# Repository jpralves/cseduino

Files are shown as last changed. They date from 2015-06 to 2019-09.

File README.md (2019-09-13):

# CSEduino

Build your Arduino from scratch - projects

See more info at http://jpralves.net/cseduino/

This tree is organized in the following way:

- ~[projects](projects) - projects created with CSEDuino board~ (Not yet)
- [boards](boards) - Designs of PCB boards for CSEduino v3 and v4 (Kicad Format)
- [workshop](workshop) - Exercises for Workshops

## The V3 Board:

Board with components:

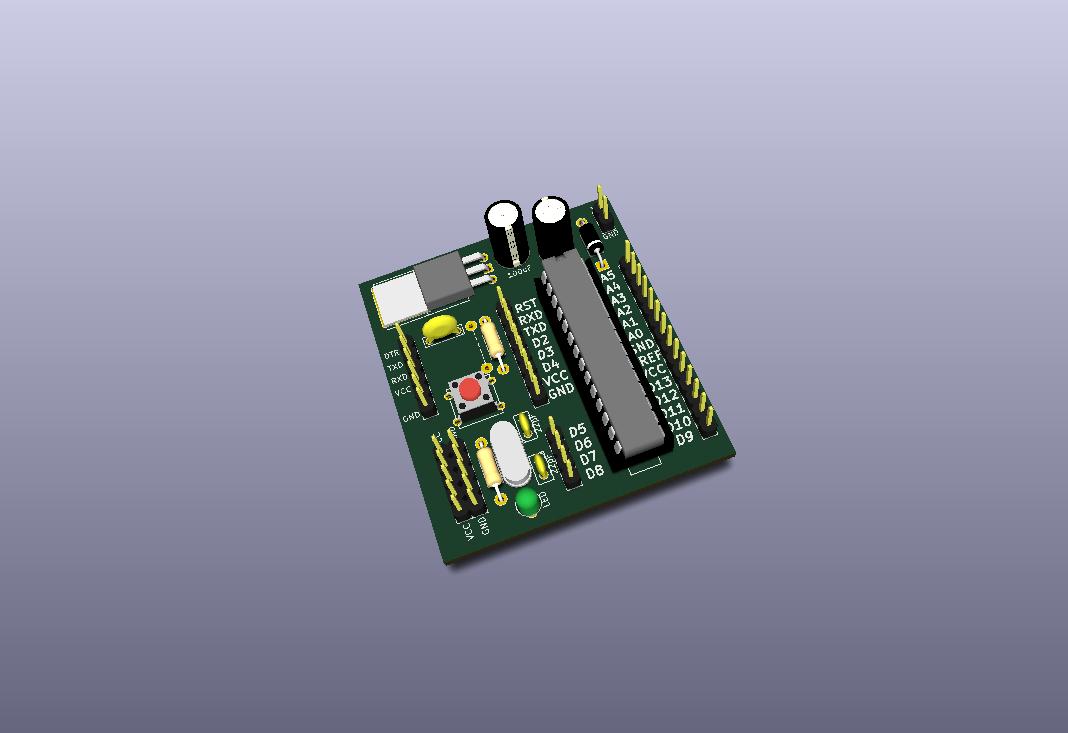
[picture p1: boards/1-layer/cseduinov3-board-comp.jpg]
cseduinov3-board-comp


## The v4 Board:

Board with components:

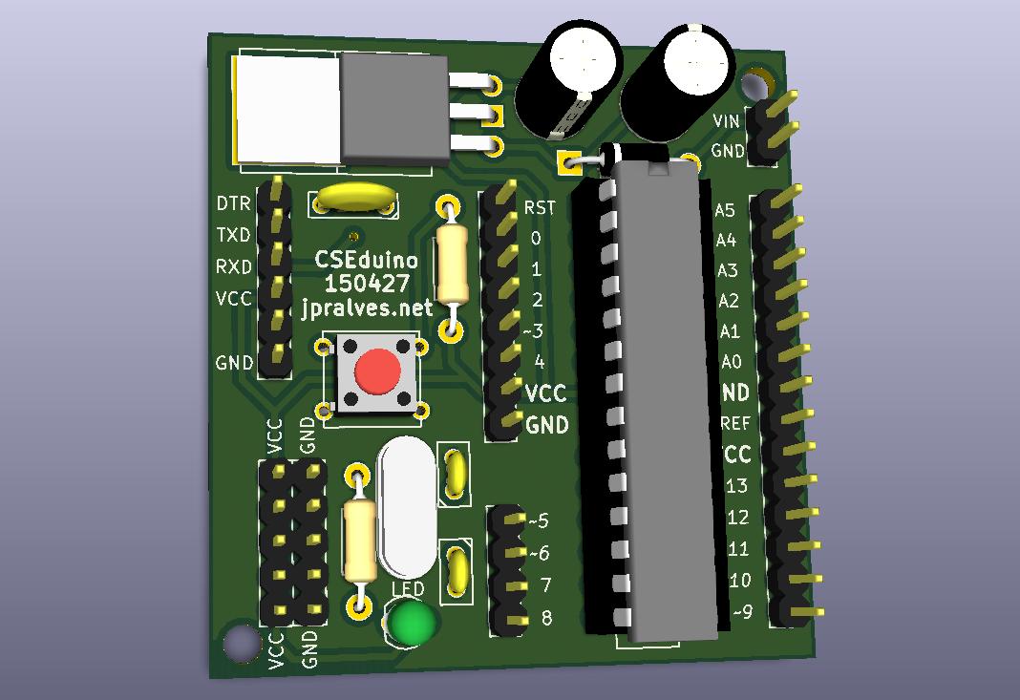
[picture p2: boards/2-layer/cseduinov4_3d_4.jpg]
cseduinov4-board-comp


Front of the board:

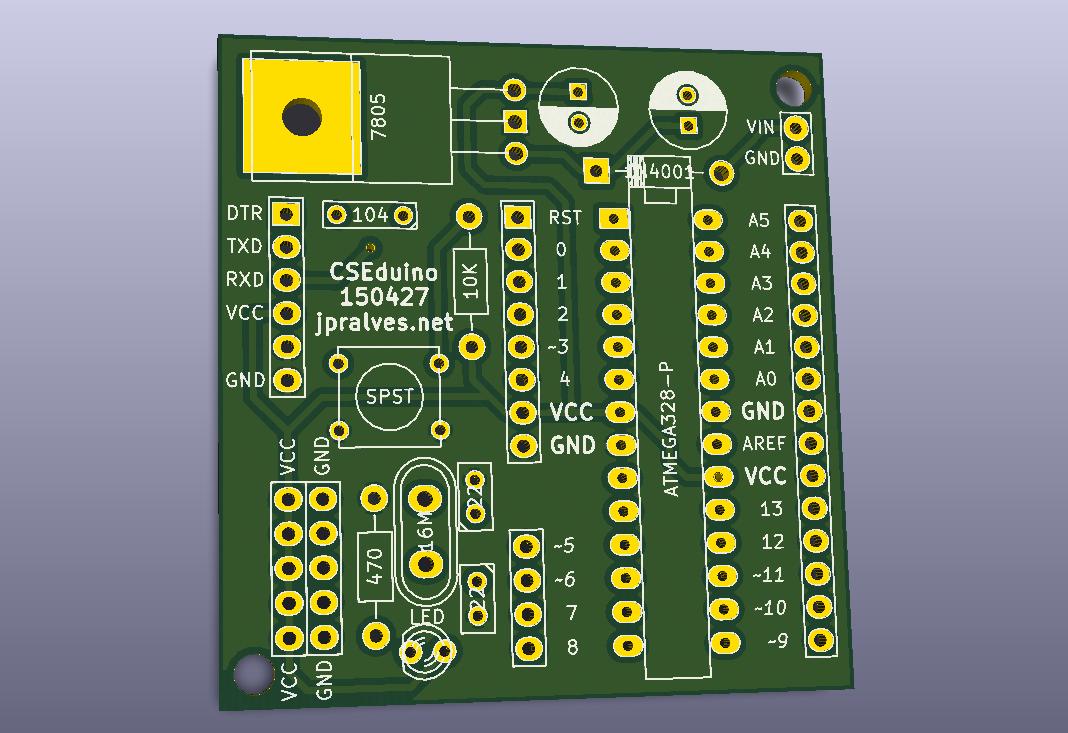
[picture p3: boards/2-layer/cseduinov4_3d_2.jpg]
cseduinov3-board


Back of the board:

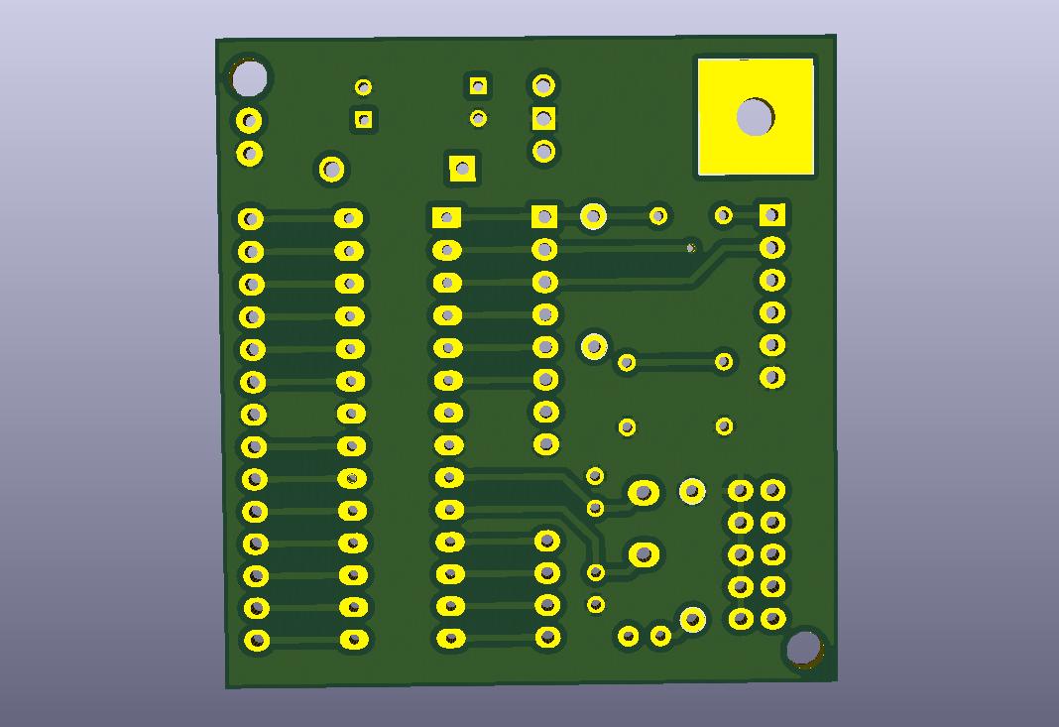
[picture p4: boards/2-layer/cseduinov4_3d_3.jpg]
cseduinov3-board-back


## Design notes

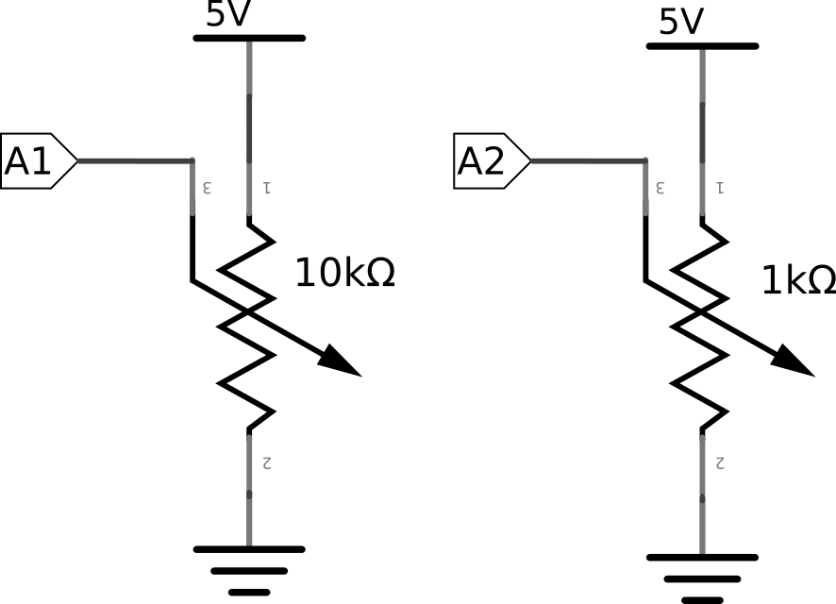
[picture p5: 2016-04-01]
workshop/2016-04-02/Theremin/VR.png

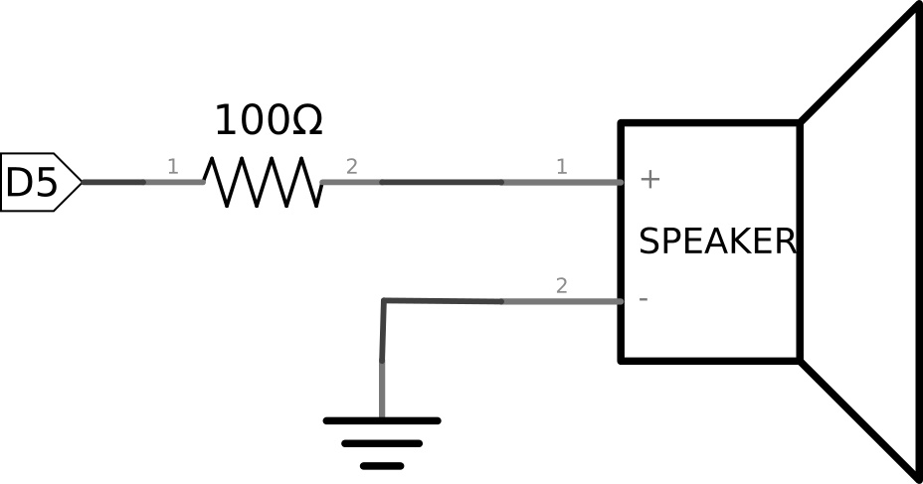
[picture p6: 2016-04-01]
workshop/2016-04-02/Morse/Buzzer.png

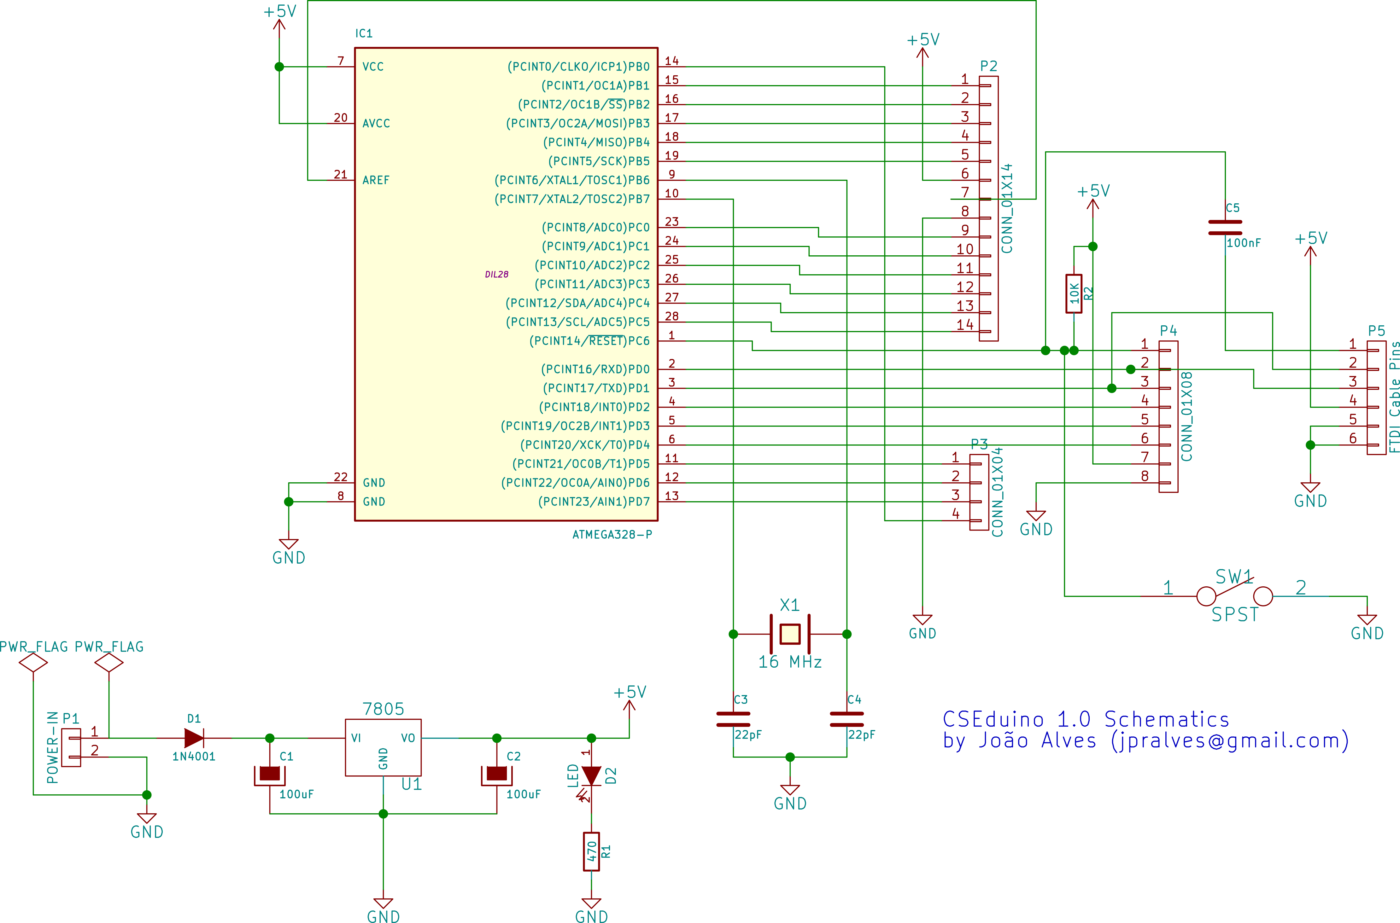
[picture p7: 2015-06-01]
boards/1-layer/cseduinov3.sch.png

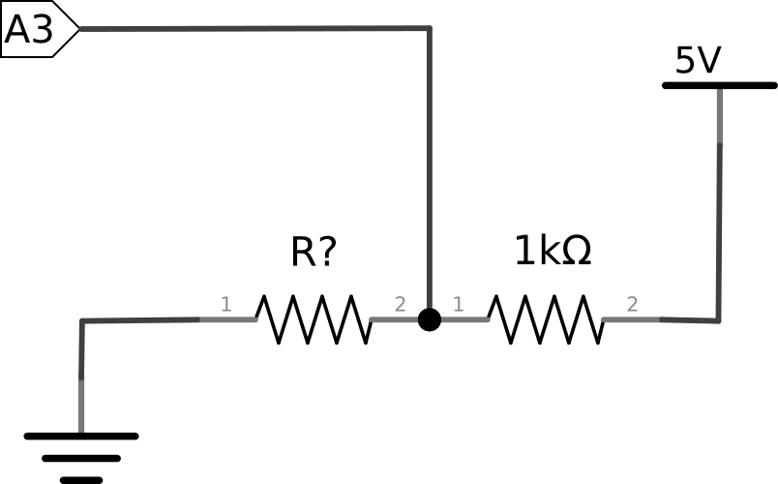
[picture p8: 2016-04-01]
workshop/2016-04-02/OhmMeter/OhmMeter.png

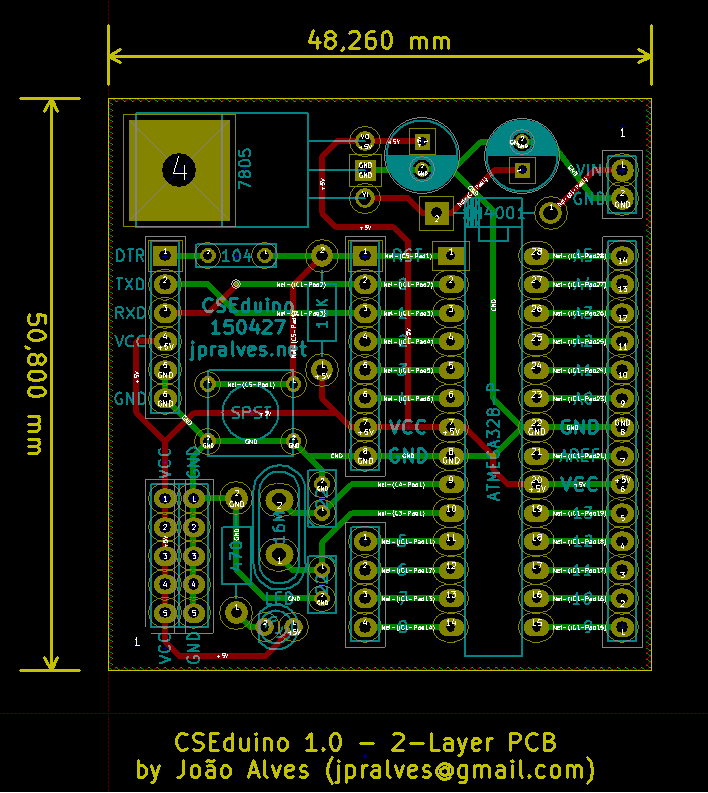
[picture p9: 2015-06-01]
boards/2-layer/cseduinov4.kicad_pcb2.png

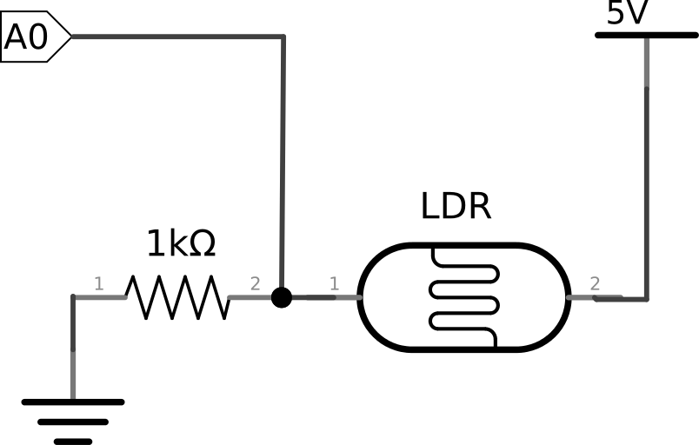
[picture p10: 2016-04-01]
workshop/2016-04-02/Photoresistor/Photoresistor.png

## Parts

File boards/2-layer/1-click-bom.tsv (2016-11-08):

References | Qty | Mouser | Description
C2, C1 | 2 | 667-ECA-1EM101 | CAPAPOL 100uF
C3, C4 | 2 | 594-CN15A220J | C 22pF Unpolarized capacitor
C5 | 1 | 594-D103Z25Z5VF63L6R | C 100nF Unpolarized capacitor
D1 | 1 | 863-1N4001G | DIODE 1N4001
D2 | 1 | 696-SLX-LX3044HD | LED
IC1 | 1 | 556-ATMEGA328P-PU | ATMEGA328P-PU PDIP28 Narrow, 16k Flash, 1kB SRAM, 512B EEPROM DIL28
IC1_SOCKET | 1 | 571-1-2199298-9 | 28P DIP SKT 300 CL LADDER
P2 | 1 | 855-M20-7821446 | CONN 01X14 Connector, single row, 01x14
P3 | 1 | 855-M20-7820446 | CONN 01X04 Connector, single row, 01x04
P4 | 1 | 855-M20-7820842 | CONN 01X08 Connector, single row, 01x08
P1 | 1 | 571-4-146278-0 | CONN 01X06 FTDI Cable Pins Connector, single row, 01x06
R1 | 1 | 603-MFR-25FBF52-470R | R 470 Resistor
R2 | 1 | 603-MFR-25FBF52-10K | R 10K Resistor
SW1 | 1 | 653-B3W-1002 | SPST Interrupteur simple
U1 | 1 | 863-NCP7805TG | 7805 Linear Regulator +5V
X1 | 1 | 520-160-20-46X | CRYSTAL 16.0000MHZ 18PF T/H

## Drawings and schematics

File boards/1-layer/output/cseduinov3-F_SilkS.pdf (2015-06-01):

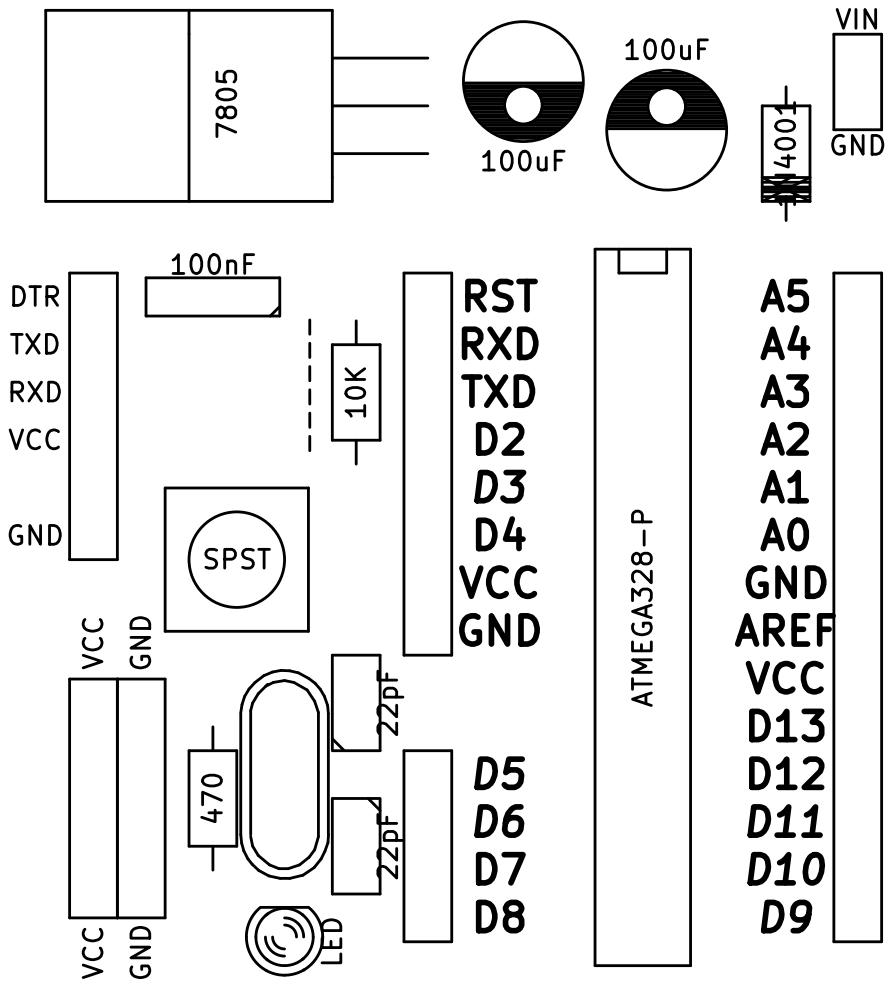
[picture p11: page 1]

VIN GND VCC GND GND
SPST7805

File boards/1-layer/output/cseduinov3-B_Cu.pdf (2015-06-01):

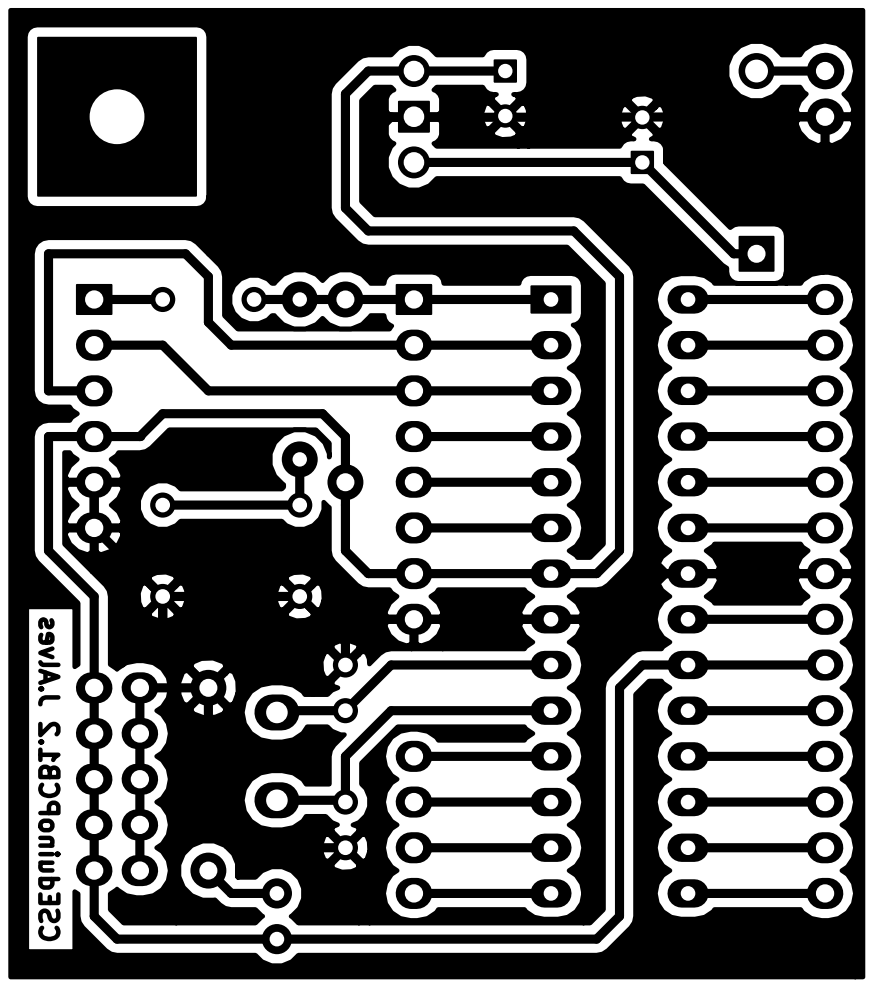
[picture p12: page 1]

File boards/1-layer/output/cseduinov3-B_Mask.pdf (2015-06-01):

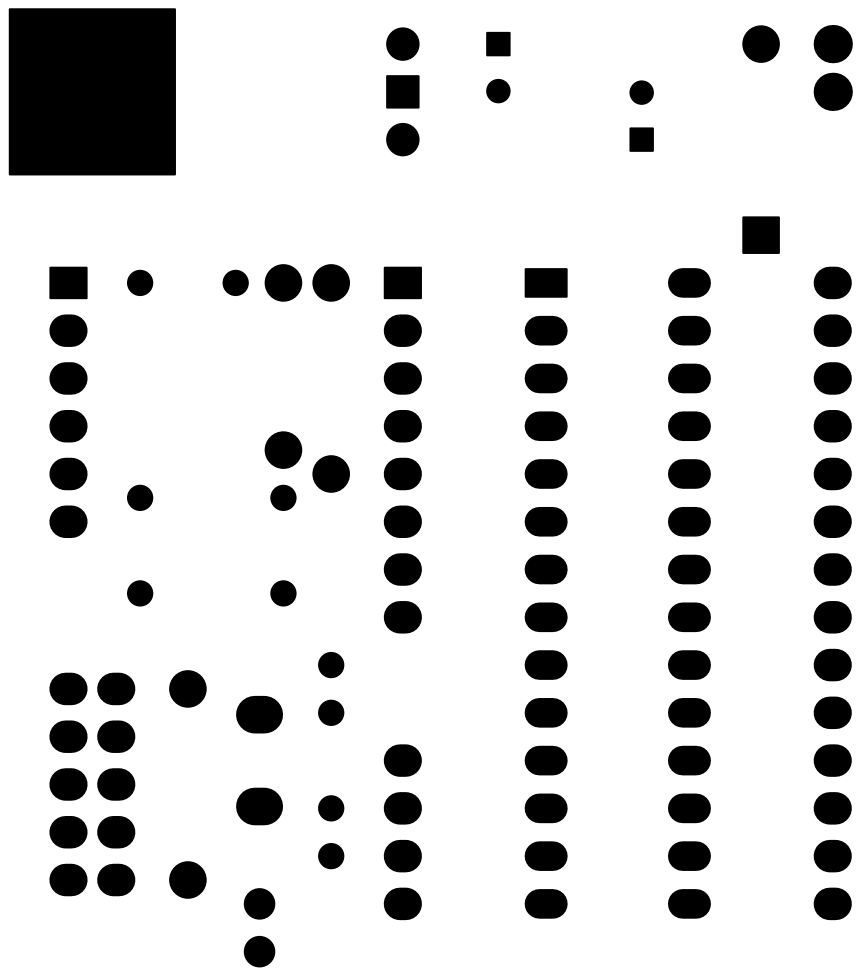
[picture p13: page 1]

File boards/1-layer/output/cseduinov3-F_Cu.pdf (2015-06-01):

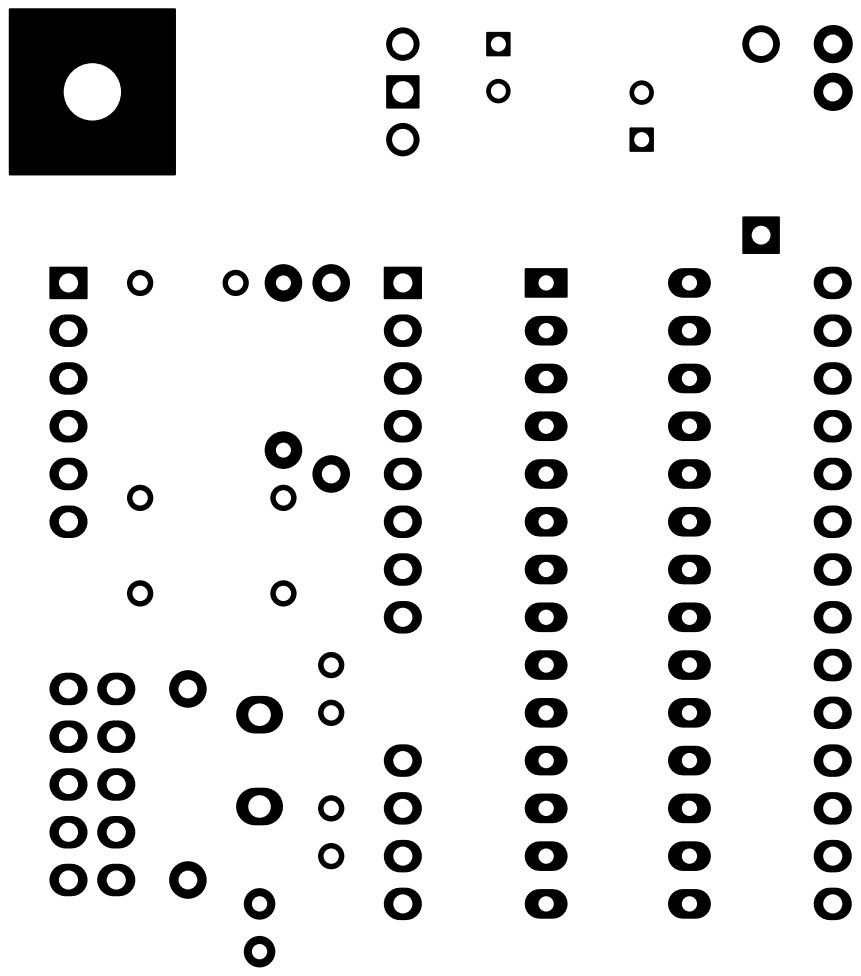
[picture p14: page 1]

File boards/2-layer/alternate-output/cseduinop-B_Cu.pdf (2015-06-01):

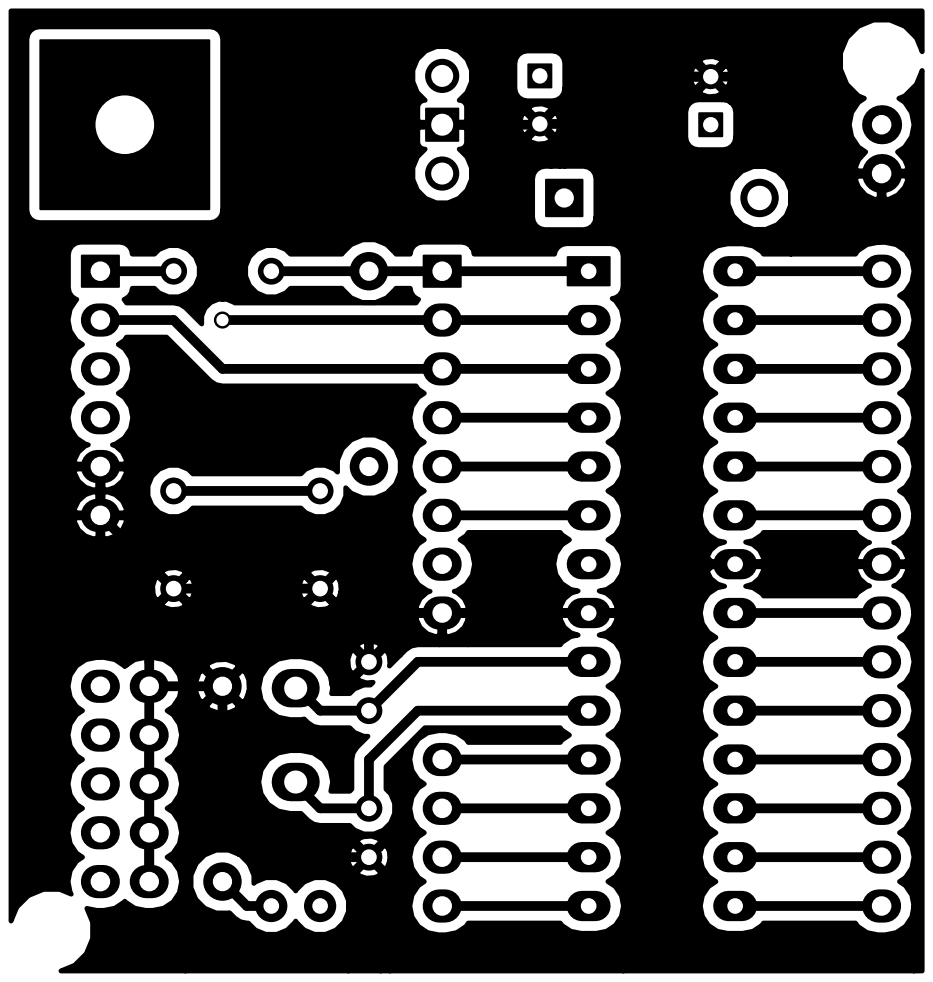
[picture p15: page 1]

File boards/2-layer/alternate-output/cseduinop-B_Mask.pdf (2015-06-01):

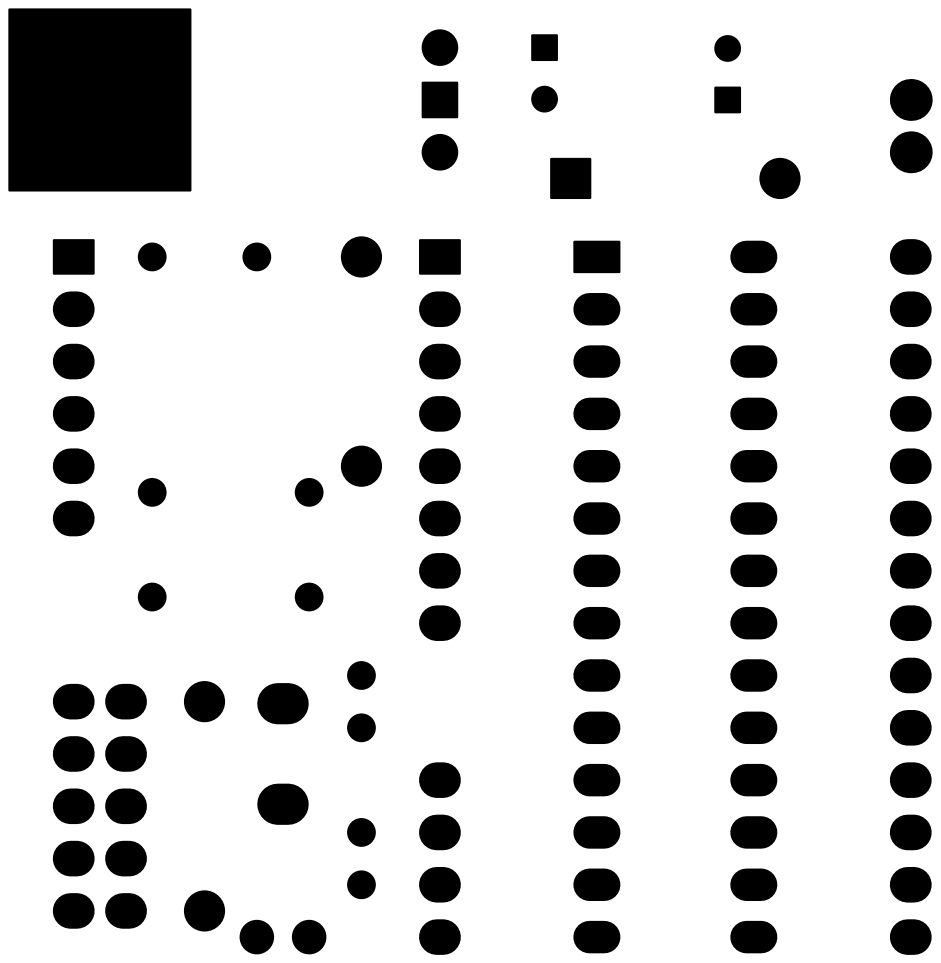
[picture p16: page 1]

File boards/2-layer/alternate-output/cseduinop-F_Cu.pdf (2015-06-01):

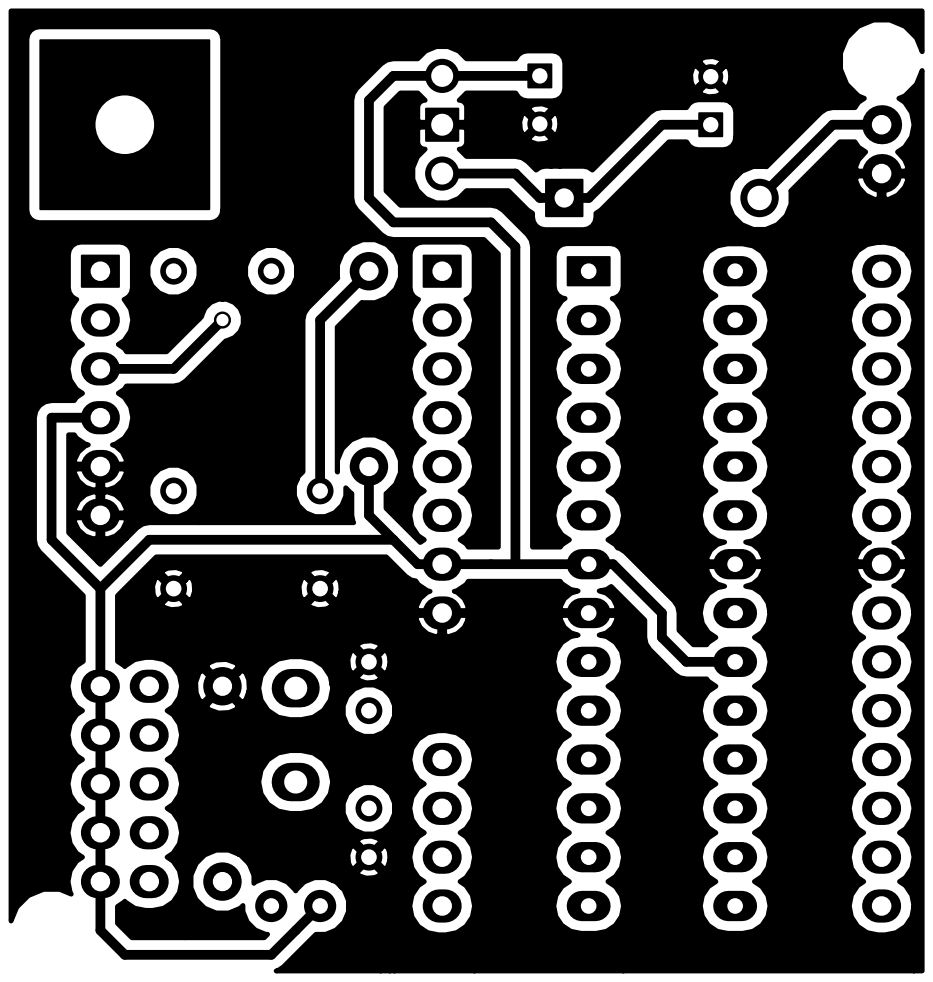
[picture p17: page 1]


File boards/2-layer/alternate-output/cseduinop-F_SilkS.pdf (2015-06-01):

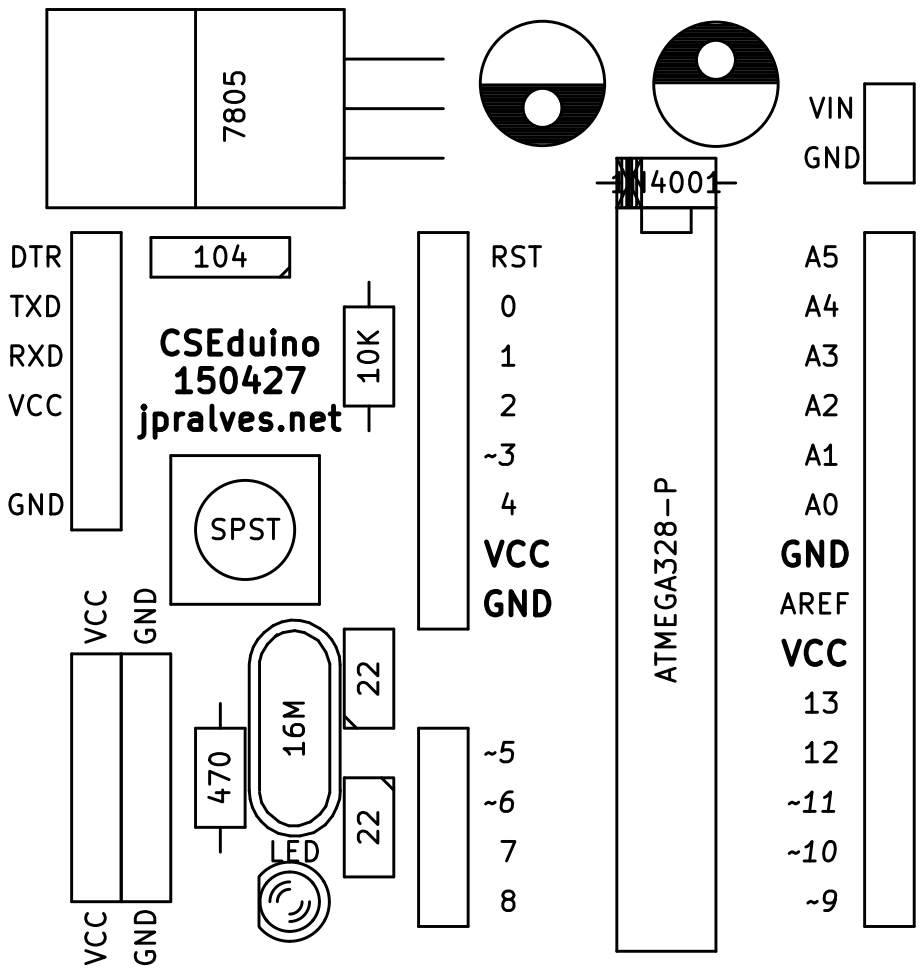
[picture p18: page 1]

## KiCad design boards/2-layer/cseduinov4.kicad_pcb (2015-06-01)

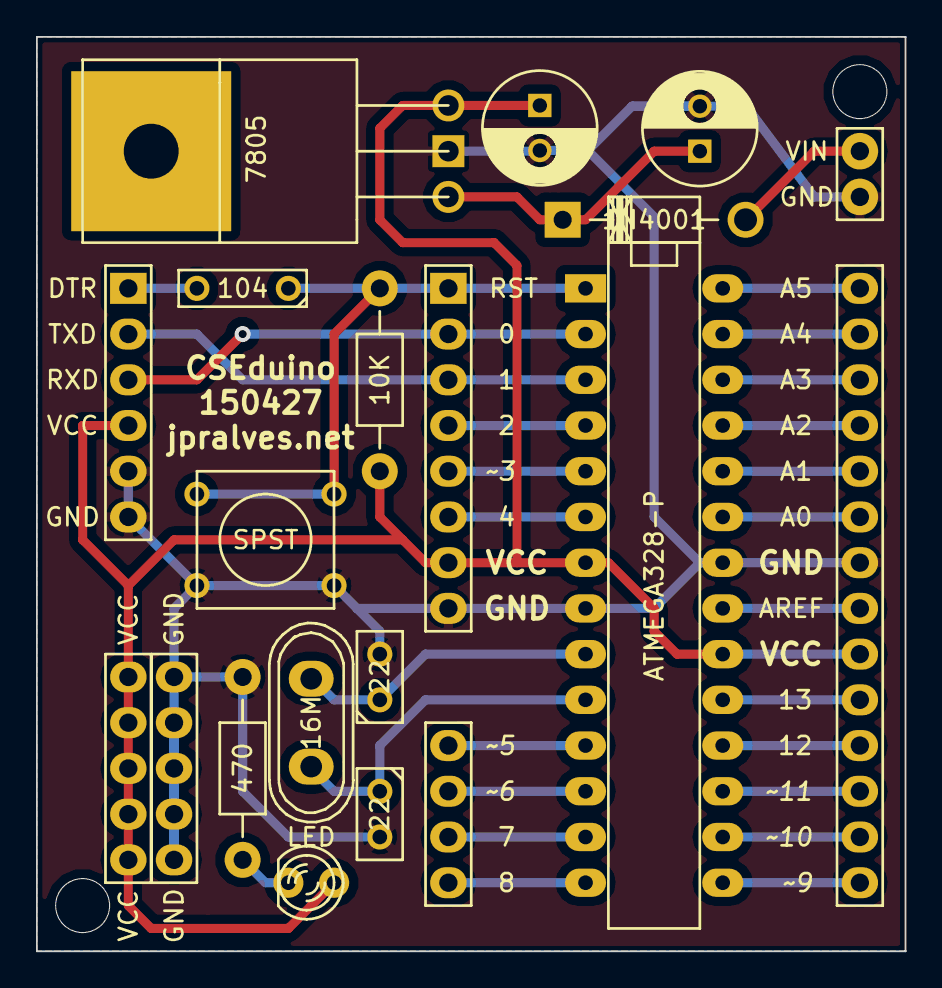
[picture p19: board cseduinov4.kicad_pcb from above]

Board: 2 copper layers, 48.3 x 50.8 mm, 18 parts (0 on the bottom side), 30 nets.

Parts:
C1, C2: 100uF; C_Radial_D6.3_L11.2_P2.5
C3, C4: 22; C1
C5: 104; C2
D1: 1N4001; Diode_DO-41_SOD81_Horizontal_RM10
D2: LED; LED-3MM
IC1: ATMEGA328-P; DIP-28__300_ELL
P1: CONN_01X02; Pin_Header_Straight_1x02
P2: CONN_01X14; Pin_Header_Straight_1x14
P3: CONN_01X04; Pin_Header_Straight_1x04
P4: CONN_01X08; Pin_Header_Straight_1x08
P5: CONN_01X06; Pin_Header_Straight_1x06
R1: 470; Resistor_Horizontal_RM10mm
R2: 10K; Resistor_Horizontal_RM10mm
SW1: SPST; SW_PUSH_SMALL
U1: 7805; LM78XX
X1: 16M; Crystal_HC50-U_Vertical

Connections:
+5V: C2.1, D2.1, IC1.7, IC1.20, P2.6, P4.7, P5.4, R2.1, U1.VO
GND: C1.2, C2.2, C3.2, C4.2, IC1.8, IC1.22, P1.2, P2.8, P4.8, P5.5, P5.6, R1.2, SW1.2, U1.GND
unnamed: C1.1, D1.2, U1.VI
unnamed: C3.1, IC1.10, X1.1
unnamed: C4.1, IC1.9, X1.2
unnamed: C5.1, IC1.1, P4.1, R2.2, SW1.1
unnamed: C5.2, P5.1
unnamed: D1.1, P1.1
unnamed: D2.2, R1.1
unnamed: IC1.2, P4.2, P5.3
unnamed: IC1.3, P4.3, P5.2
unnamed: IC1.4, P4.4
unnamed: IC1.5, P4.5
unnamed: IC1.6, P4.6
unnamed: IC1.11, P3.1
unnamed: IC1.12, P3.2
unnamed: IC1.13, P3.3
unnamed: IC1.14, P3.4
unnamed: IC1.15, P2.1
unnamed: IC1.16, P2.2
unnamed: IC1.17, P2.3
unnamed: IC1.18, P2.4
unnamed: IC1.19, P2.5
unnamed: IC1.21, P2.7
unnamed: IC1.23, P2.9
unnamed: IC1.24, P2.10
unnamed: IC1.25, P2.11
unnamed: IC1.26, P2.12
unnamed: IC1.27, P2.13
unnamed: IC1.28, P2.14

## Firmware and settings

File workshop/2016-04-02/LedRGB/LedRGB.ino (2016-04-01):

/*
* Code for cross-fading 3 LEDs, red, green and blue (RGB) 
* To create fades, you need to do two things: 
*  1. Describe the colors you want to be displayed
*  2. List the order you want them to fade in
*
* DESCRIBING A COLOR:
* A color is just an array of three percentages, 0-100, 
*  controlling the red, green and blue LEDs
*
* Red is the red LED at full, blue and green off
*   int red = { 100, 0, 0 }
* Dim white is all three LEDs at 30%
*   int dimWhite = {30, 30, 30}
* etc.
*
* Some common colors are provided below, or make your own
* 
* LISTING THE ORDER:
* In the main part of the program, you need to list the order 
*  you want to colors to appear in, e.g.
*  crossFade(red);
*  crossFade(green);
*  crossFade(blue);
*
* Those colors will appear in that order, fading out of 
*    one color and into the next  
*
* In addition, there are 5 optional settings you can adjust:
* 1. The initial color is set to black (so the first color fades in), but 
*    you can set the initial color to be any other color
* 2. The internal loop runs for 1020 interations; the 'wait' variable
*    sets the approximate duration of a single crossfade. In theory, 
*    a 'wait' of 10 ms should make a crossFade of ~10 seconds. In 
*    practice, the other functions the code is performing slow this 
*    down to ~11 seconds on my board. YMMV.
* 3. If 'repeat' is set to 0, the program will loop indefinitely.
*    if it is set to a number, it will loop that number of times,
*    then stop on the last color in the sequence. (Set 'return' to 1, 
*    and make the last color black if you want it to fade out at the end.)
* 4. There is an optional 'hold' variable, which pasues the 
*    program for 'hold' milliseconds when a color is complete, 
*    but before the next color starts.
* 5. Set the DEBUG flag to 1 if you want debugging output to be
*    sent to the serial monitor.
*
*    The internals of the program aren't complicated, but they
*    are a little fussy -- the inner workings are explained 
*    below the main loop.
*
* April 2007, Clay Shirky <clay.shirky@nyu.edu> 
*/ 

// Output
const int redPin = 6;  // Red LED
const int grnPin = 7;  // Green LED
const int bluPin = 8;  // Blue LED

// Color arrays
int black[3]  = { 0, 0, 0 };
int white[3]  = { 100, 100, 100 };
int red[3]    = { 100, 0, 0 };
int green[3]  = { 0, 100, 0 };
int blue[3]   = { 0, 0, 100 };
int yellow[3] = { 40, 95, 0 };
int dimWhite[3] = { 30, 30, 30 };
// etc.

// Set initial color
int redVal = black[0];
int grnVal = black[1]; 
int bluVal = black[2];

int wait = 10;      // 10ms internal crossFade delay; increase for slower fades
int hold = 0;       // Optional hold when a color is complete, before the next crossFade
int DEBUG = 1;      // DEBUG counter; if set to 1, will write values back via serial
int loopCount = 60; // How often should DEBUG report?
int repeat = 3;     // How many times should we loop before stopping? (0 for no stop)
int j = 0;          // Loop counter for repeat

// Initialize color variables
int prevR = redVal;
int prevG = grnVal;
int prevB = bluVal;

// Set up the LED outputs
void setup()
{
  pinMode(redPin, OUTPUT);   // sets the pins as output
  pinMode(grnPin, OUTPUT);   
  pinMode(bluPin, OUTPUT); 

  if (DEBUG) {           // If we want to see values for debugging...
    Serial.begin(9600);  // ...set up the serial ouput 
  }
}

// Main program: list the order of crossfades
void loop()
{
  crossFade(red);
  crossFade(green);
  crossFade(blue);
  crossFade(yellow);

  if (repeat) { // Do we loop a finite number of times?
    j += 1;
    if (j >= repeat) { // Are we there yet?
      exit(j);         // If so, stop.
    }
  }
}

/* BELOW THIS LINE IS THE MATH -- YOU SHOULDN'T NEED TO CHANGE THIS FOR THE BASICS
* 
* The program works like this:
* Imagine a crossfade that moves the red LED from 0-10, 
*   the green from 0-5, and the blue from 10 to 7, in
*   ten steps.
*   We'd want to count the 10 steps and increase or 
*   decrease color values in evenly stepped increments.
*   Imagine a + indicates raising a value by 1, and a -
*   equals lowering it. Our 10 step fade would look like:
* 
*   1 2 3 4 5 6 7 8 9 10
* R + + + + + + + + + +
* G   +   +   +   +   +
* B     -     -     -
* 
* The red rises from 0 to 10 in ten steps, the green from 
* 0-5 in 5 steps, and the blue falls from 10 to 7 in three steps.
* 
* In the real program, the color percentages are converted to 
* 0-255 values, and there are 1020 steps (255*4).
* 
* To figure out how big a step there should be between one up- or
* down-tick of one of the LED values, we call calculateStep(), 
* which calculates the absolute gap between the start and end values, 
* and then divides that gap by 1020 to determine the size of the step  
* between adjustments in the value.
*/

int calculateStep(int prevValue, int endValue) {
  int step = endValue - prevValue; // What's the overall gap?
  if (step) {                      // If its non-zero, 
    step = 1020/step;              //   divide by 1020
  } 
  return step;
}

/* The next function is calculateVal. When the loop value, i,
*  reaches the step size appropriate for one of the
*  colors, it increases or decreases the value of that color by 1. 
*  (R, G, and B are each calculated separately.)
*/

int calculateVal(int step, int val, int i) {

  if ((step) && i % step == 0) { // If step is non-zero and its time to change a value,
    if (step > 0) {              //   increment the value if step is positive...
      val += 1;           
    } 
    else if (step < 0) {         //   ...or decrement it if step is negative
      val -= 1;
    } 
  }
  // Defensive driving: make sure val stays in the range 0-255
  if (val > 255) {
    val = 255;
  } 
  else if (val < 0) {
    val = 0;
  }
  return val;
}

/* crossFade() converts the percentage colors to a 
*  0-255 range, then loops 1020 times, checking to see if  
*  the value needs to be updated each time, then writing
*  the color values to the correct pins.
*/

void crossFade(int color[3]) {
  // Convert to 0-255
  int R = (color[0] * 255) / 100;
  int G = (color[1] * 255) / 100;
  int B = (color[2] * 255) / 100;

  int stepR = calculateStep(prevR, R);
  int stepG = calculateStep(prevG, G); 
  int stepB = calculateStep(prevB, B);

  for (int i = 0; i <= 1020; i++) {
    redVal = calculateVal(stepR, redVal, i);
    grnVal = calculateVal(stepG, grnVal, i);
    bluVal = calculateVal(stepB, bluVal, i);

    analogWrite(redPin, 255-redVal);   // Write current values to LED pins
    analogWrite(grnPin, 255-grnVal);      
    analogWrite(bluPin, 255-bluVal); 

    delay(wait); // Pause for 'wait' milliseconds before resuming the loop

    if (DEBUG) { // If we want serial output, print it at the 
      if (i == 0 or i % loopCount == 0) { // beginning, and every loopCount times
        Serial.print("Loop/RGB: #");
        Serial.print(i);
        Serial.print(" | ");
        Serial.print(redVal);
        Serial.print(" / ");
        Serial.print(grnVal);
        Serial.print(" / ");  
        Serial.println(bluVal); 
      } 
      DEBUG += 1;
    }
  }
  // Update current values for next loop
  prevR = redVal; 
  prevG = grnVal; 
  prevB = bluVal;
  delay(hold); // Pause for optional 'wait' milliseconds before resuming the loop
}

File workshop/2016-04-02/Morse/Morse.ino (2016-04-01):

/*
    _____ _____ _____   _     _            ___ 
   |     |   __|   __|_| |_ _|_|___ ___   | | |
   |   --|__   |   __| . | | | |   | . |  |_  |
   |_____|_____|_____|___|___|_|_|_|___|    |_|

  Morse.ino

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
  Description:
	Translates text to Morse Code - Sound and Light

	The circuit:
	* Buzzer - Pin 5
	* Led - Pin 13
	 	
  Notes: 
  -
      
  Links:
  * CSEduino: http://jpralves.net/cseduino
  * Sources: https://github.com/jpralves/cseduino/workshop

	Created on 2016-Apr-1
	By Joao Alves <jpralves@gmail.com>

  ----------------------------------------------------------------------- */

#define DOT 1
#define DASH 2

#define note 1200

const int buzzerPin = 5;
const int ledPin =  13;

int dotLen = 100;                 
int dashLen = dotLen * 3;
int betweenChars = dotLen * 2;

char characters[] = { 
'a', 'b', 'c', 'd', 'e', 'f', 
'g', 'h', 'i', 'j', 'k', 'l',
'm', 'n', 'o', 'p', 'q', 'r', 
's', 't', 'u', 'v', 'w', 'x', 
'y', 'z', '0', '1', '2', '3', 
'4', '5', '6', '7', '8', '9'};

long morseCode[] = {
 DOT  + (DASH << 2),
 DASH + (DOT  << 2) + (DOT  << 4) + (DOT  << 6),
 DASH + (DOT  << 2) + (DASH << 4) + (DOT  << 6),
 DASH + (DOT  << 2) + (DOT  << 4),
 DOT,
 DOT  + (DOT  << 2) + (DASH << 4) + (DOT  << 6),
 DASH + (DASH << 2) + (DOT  << 4),
 DOT  + (DOT  << 2) + (DOT  << 4) + (DOT  << 6),
 DOT  + (DOT  << 2),
 DOT  + (DASH << 2) + (DASH << 4) + (DASH << 6),
 DASH + (DOT  << 2) + (DASH << 4),
 DOT  + (DASH << 2) + (DOT  << 4) + (DOT  << 6),
 DASH + (DASH << 2),
 DASH + (DOT  << 2),
 DASH + (DASH << 2) + (DASH << 4),
 DOT  + (DASH << 2) + (DASH << 4) + (DOT  << 6),
 DASH + (DASH << 2) + (DOT  << 4) + (DASH << 6),
 DOT  + (DASH << 2) + (DOT  << 4),
 DOT  + (DOT  << 2) + (DOT  << 4),
 DASH,
 DOT  + (DOT  << 2) + (DASH << 4),
 DOT  + (DOT  << 2) + (DOT  << 4) + (DASH << 6),
 DOT  + (DASH << 2) + (DASH << 4),
 DASH + (DOT  << 2) + (DOT  << 4) + (DASH << 6),
 DASH + (DOT  << 2) + (DASH << 4) + (DASH << 6),
 DASH + (DASH << 2) + (DOT  << 4) + (DOT  << 6),
 DASH + (DASH << 2) + (DASH << 4) + (DASH << 6) + (DASH << 8),
 DOT  + (DASH << 2) + (DASH << 4) + (DASH << 6) + (DASH << 8),
 DOT  + (DOT  << 2) + (DASH << 4) + (DASH << 6) + (DASH << 8),
 DOT  + (DOT  << 2) + (DOT  << 4) + (DASH << 6) + (DASH << 8),
 DOT  + (DOT  << 2) + (DOT  << 4) + (DOT  << 6) + (DASH << 8),
 DOT  + (DOT  << 2) + (DOT  << 4) + (DOT  << 6) + (DOT  << 8),
 DASH + (DOT  << 2) + (DOT  << 4) + (DOT  << 6) + (DOT  << 8),
 DASH + (DASH << 2) + (DOT  << 4) + (DOT  << 6) + (DOT  << 8),
 DASH + (DASH << 2) + (DASH << 4) + (DOT  << 6) + (DOT  << 8),
 DASH + (DASH << 2) + (DASH << 4) + (DASH << 6) + (DOT  << 8)
};

void playMorse(char c) {
  int i;
  for(i=0; i<sizeof(characters)/sizeof(char);i++) {
    if (c == characters[i])
      break;
  }
  if (i<sizeof(characters)/sizeof(char)) {
    long code = morseCode[i];
    while (code>0) {
      if ((code & 3) == DOT)
        morseDot();
      else
        morseDash();
      code>>=2; 
      morseStop(betweenChars);   
    }
    morseStop(betweenChars);
  } else {
    morseStop(betweenChars);
  }
}

void upSignal(int timeLen) {
  digitalWrite(ledPin, HIGH);
  tone(buzzerPin, note, timeLen);
  delay(timeLen);             
}

// DOT
void morseDot() {
  upSignal(dotLen);
  Serial.print(".");
}

// DASH
void morseDash() {
  upSignal(dashLen);  
  Serial.print("-");
}

void morseStop(int delayTime) {
  digitalWrite(ledPin, LOW);   
  noTone(buzzerPin);	    
  delay(delayTime);        
}

void setup() {                
  pinMode(ledPin, OUTPUT); 
  pinMode(buzzerPin, OUTPUT);
  Serial.begin(9600);
}

int enter = 0;

void loop() { 
  if (Serial.available() > 0) { 
    byte incomingByte = Serial.read();
    byte tmp = toLowerCase(incomingByte);
    playMorse(tmp);
    enter = 1;
  } else {
    if (enter == 1) {
      Serial.println();
      enter = 0;
    }
  }
}

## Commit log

2015-06-01 Added files for cseduino v3 - 1-layer PCB Added files for cseduino v4 - 2-layer PCB
    [cseduinov3.kicad_pcb, cseduinov3.sch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]
2015-06-01 added details for 1-layer board and 2-layer board
    Added files for 1-layer PCB - CSEduino v3
    Added files for 2-layer PCB - CSEduino v4
2016-04-01 Update Button.ino
    correct buttonPin
    [Button.ino]
2016-11-08 Added BOM in 1-click format
    Added BOM in 1-click format
    [1-click-bom.tsv]

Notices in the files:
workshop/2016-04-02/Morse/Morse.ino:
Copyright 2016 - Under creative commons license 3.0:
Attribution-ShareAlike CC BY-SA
